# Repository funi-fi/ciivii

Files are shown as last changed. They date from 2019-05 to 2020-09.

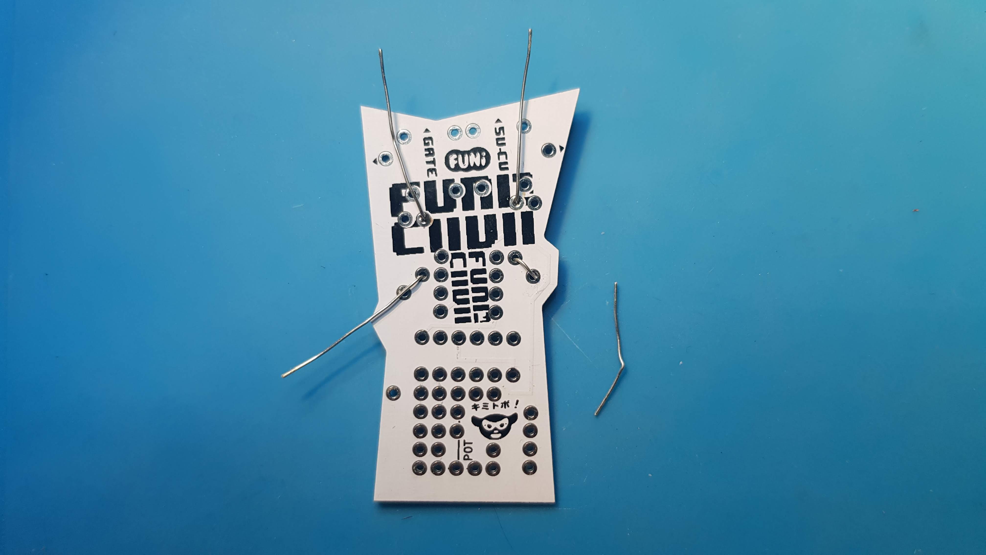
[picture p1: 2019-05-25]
Pics/CiiVii_Solder_Guide/20190522_220450.jpg

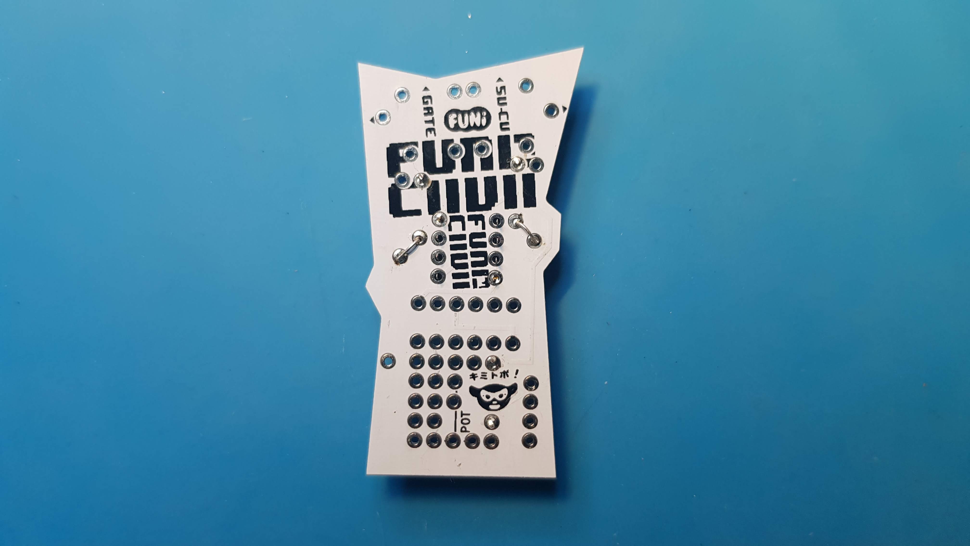
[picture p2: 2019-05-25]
Pics/CiiVii_Solder_Guide/20190522_221058.jpg

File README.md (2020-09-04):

# Funifi CiiVii
### Analog synth CV & gate controller




### Compact CV & gate controller

FuniFi CiiVii is a compact, programmable control voltage (0-5V CV&gate) controller for synthesizers with analog inputs. There is a popular ATtiny85 microcontroller in the heart of the device which can be progrmmed with Arduino IDE and collection of example patches for sending analog voltages via 12Bit DAC and protective OpAmp. Assembly is easy, just a handful of inecxpensive componets and through-hole board layout. 

Funifi CiiVii is shines with semimodular synths or small Eurorack kits, where extra CV or Gate control is welcome without expensive or large external devices. One CV output 0-5V and one gate output can be programmed to do whatever you want them to do. Just randomising the analog voltage seem to give hours of fun when plugged to various inputs in the analog synthesiser.

### How to get it

There will be DIY kits available when next round of testing has cleared some concerns. The circuit can be build on breadboard very easily for the hasty & geeky ones. If you would be interested in beta testing either the soldering, or coding, or both, don't hesitate to contact, few test kits will be avilable shortly.

### Make it

Follow the guides in the Github Wiki: https://github.com/funi-fi/ciivii/wiki

Digistump Arduino guide
https://digistump.com/wiki/digispark/tutorials/connecting

### Bill of Materials

TBD

### Open hardware

Funifi CiiVIi is open source hardware and open source software, in short do whatever you like with them, as long as you share your derivatives under same granted freedom.

### Proto-alert

Use at yuour own risk, no guarantee can be granted for unikely but possible damage to the device itself or where it is connected. CiiVii is a prototype. It has been tested but there is a lot of room for improvement. Below are few issues on the todo list. All tips & suggestions welcome.

Please check the open issues here:
https://github.com/funi-fi/ciivii/issues/1

### To-do

~~explore OpAmp resistor values for better voltage range~~
- explore Attiny85 firmware variation for uploading code without disconneting the device (/reset button?)
- source better disc potentimeter with 3pin/2.54pitch footprint
- scale potentiometer values for wider range in the lower resistancies
- BOM

--------

### Links

For controlling MIDI, check out FuniFi Midistik: 
https://github.com/funi-fi/midistik

FuniFi Playful DIY synth accessories
https://www.instagram.com/funifimusic/

Board manufactured by PCBWay
https://www.pcbway.com/project/shareproject/Funifi_CiiVIi.html

### Hardware Version history
- V0.1 12.4.2019

- V0.1 15.4.2018

### Acknowedgements
For me, this journey started in Tapei, deep bow for Dimension Plus for hosting several gatherings
http://dimensionplus.co/en/index.html

The main source for new knowledge on DIY PCB & Workshopology from Marc Dusseiller & 8BitMixtape hackers

http://www.dusseiller.ch/labs/

http://neo.8bitmixtape.cc/

Amazing SVG2Shenzhem Inkscape PCB design tool by Budi Prakosa

https://github.com/badgeek/svg2shenzhen

https://www.patreon.com/badgeek/posts

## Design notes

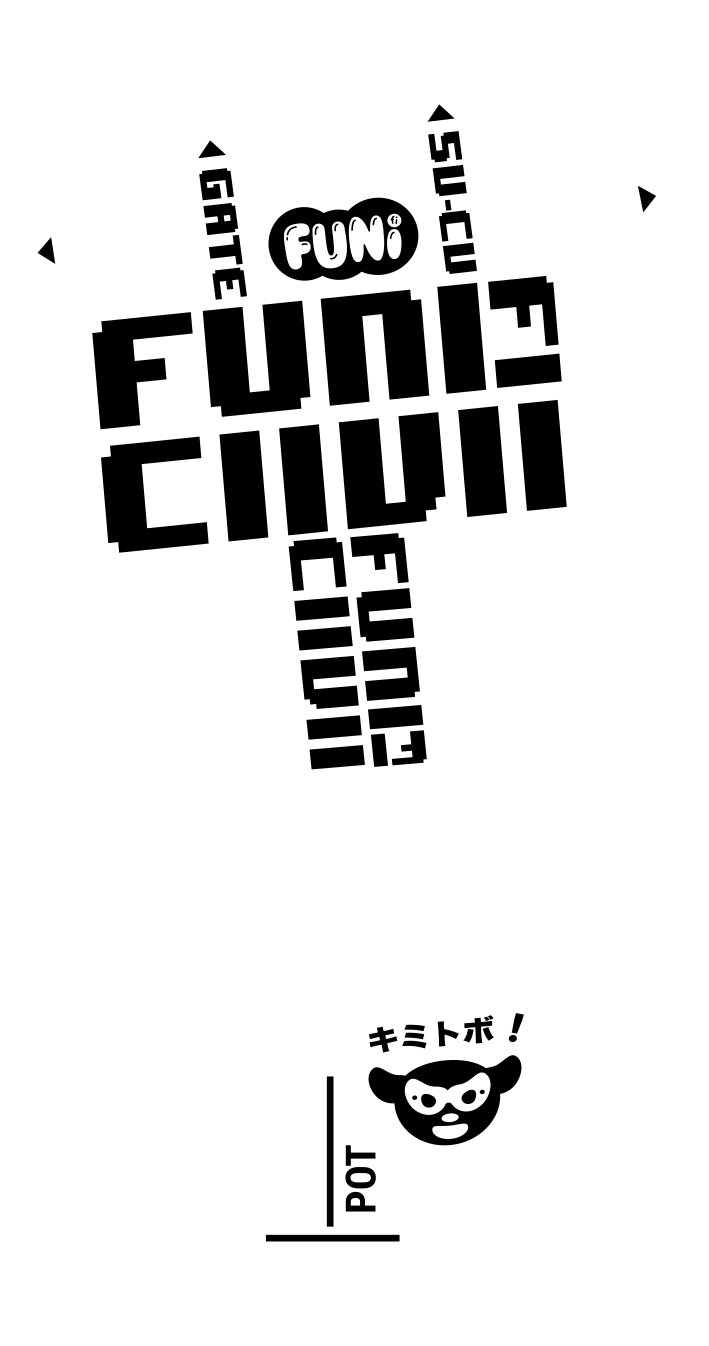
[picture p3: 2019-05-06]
Hardware/.svg2shenzhen-cache/images/F.Silk_g29462.png

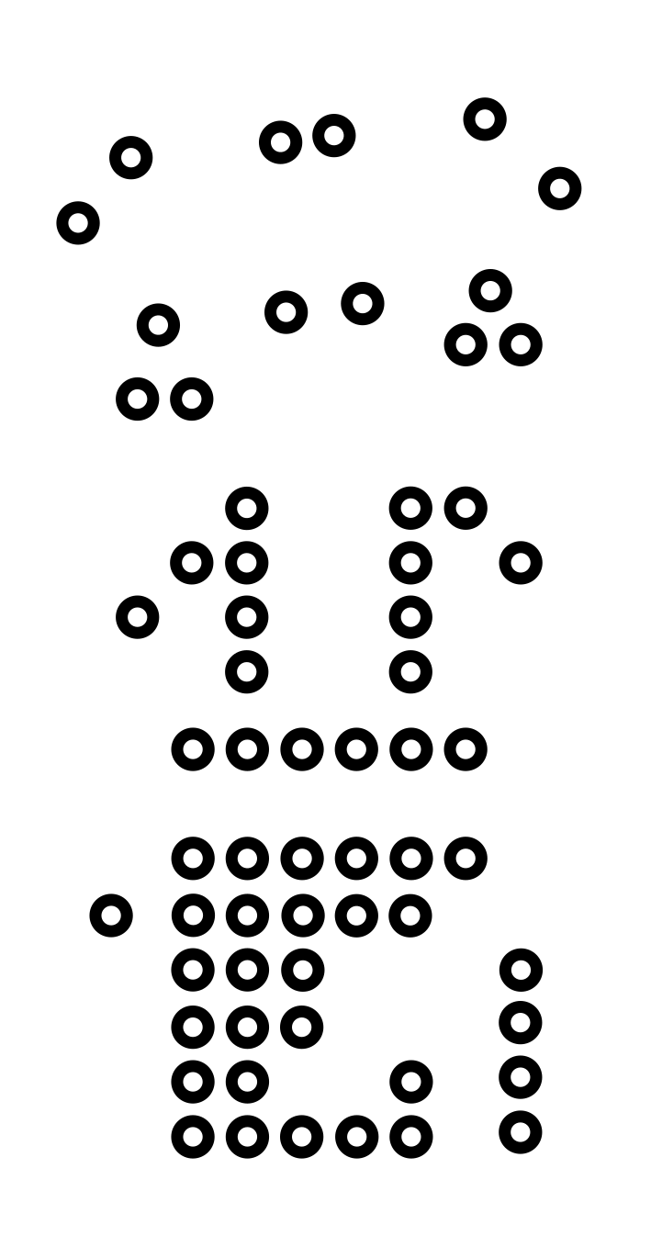
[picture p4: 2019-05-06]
Hardware/.svg2shenzhen-cache/images/B.Mask_g29454.png

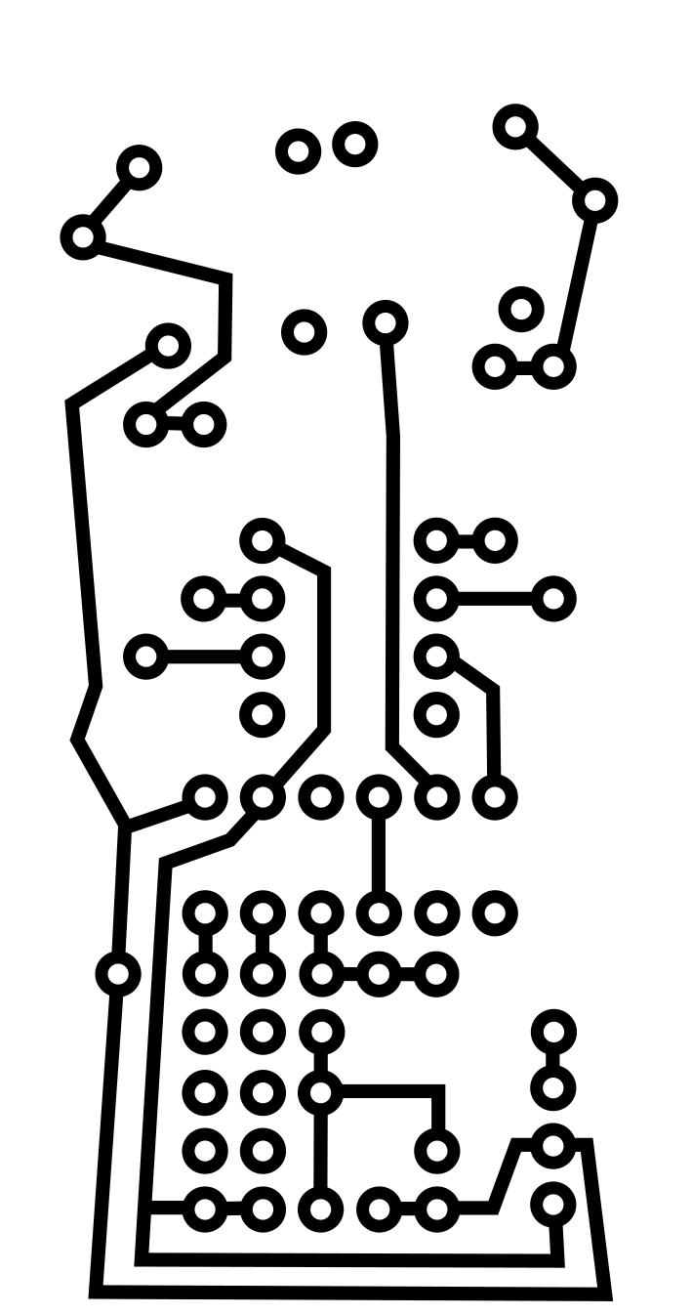
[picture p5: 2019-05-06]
Hardware/.svg2shenzhen-cache/images/B.Cu_g29452.png

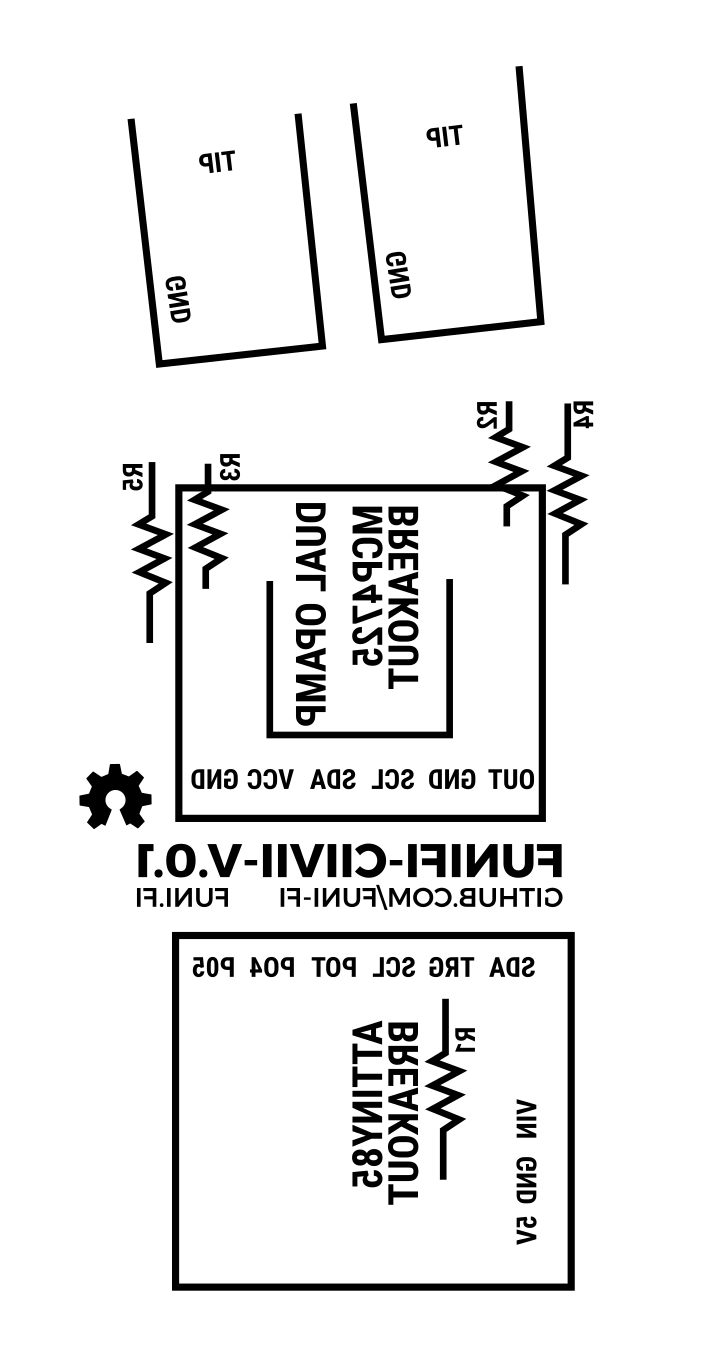
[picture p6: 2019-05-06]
Hardware/.svg2shenzhen-cache/images/B.Silk_g29456.png

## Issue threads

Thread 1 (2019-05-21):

OpAmp resistors decrease the output range

funi-fi, 2019-05-21:
OpMap feedback resistors decrease the output range to about 0-3V.

funi-fi, 2019-05-21:
R4 & R5 feedback resistors are not needed, but OpAmp inverted inputs (-) need connection to outputs. This is easiest leaving bit of resistor leg for R2 & R3 through the hole from the OpAmp output and solder the leg to the nearby inverted inputs. See the pic.:

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

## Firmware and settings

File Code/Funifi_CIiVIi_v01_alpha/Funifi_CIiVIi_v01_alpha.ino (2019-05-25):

  /*

  FUNI.FI CIIVII, HARDWARE VERSION 0.1
  _________ .__.______   ____.__.__ 
  \_   ___ \|__|__\   \ /   /|__|__|
  /    \  \/|  |  |\   Y   / |  |  |
  \     \___|  |  | \     /  |  |  |
   \______  /__|__|  \___/   |__|__|
          \/   
               
  ATTiny85 Pins
  ===================
                                 _______
                                |   U   |                                     
         (available) D5/A0  PB5-|       |- VCC                                
              Pot -> D3/A3  PB3-| ATTINY|- PB2  D2/A1 <- DAC I2C SCL
         (available) D4/A2  PB4-|   85  |- PB1  D1    -> Gate out
                            GND-|       |- PB0  D0    -> DAC I2C SDA
                                |_______|
  Digispark pin order
  ===================                     

  P5  Available D5/A0 / Reset (Some Digistump clones need firmware update for enabling D/A
  P4  Available D4/A3 / PWM 
  P3  A3    Analog in, pot
  P2  SCL   To DAC clock
  P1  D1    Gate out
  P0  SDA   To DAC data


  * Funi.fi CV randomiser experimentations by Tuomo Tammenpää (@kimitobo)
    https://github.com/funi-fi
    
  * MCP4725 DAC 12Bit bithsift lookup table code based on code written by Mark VandeWettering:
    http://brainwagon.org/2011/02/24/arduino-mcp4725-breakout-board/
    Discovered via Sparkfun MCP4725 hookup guide
    https://learn.sparkfun.com/tutorials/mcp4725-digital-to-analog-converter-hookup-guide

  * SVG-to-Shenzhen Inkscape to Kicad DIY PCB pipeline by Budi Prakosa
    https://github.com/badgeek/svg2shenzhen

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
 */

#include <TinyWireM.h>            // I2C library for Attiny85
#define MCP4725_ADDR 0x60         // Notice! MCP4725 can be modified to address 0x61 soldering the bridge

#define POTI          A3          // P3(A3) pin on Digispark
#define GATE_OUT      1           // P1 pin on Digispark
#define GATE_TIME     3           // Gate duration
#define BUFFER        10          // Minimum delay for sending the value to DAC
#define POT_MIN       570         // 10K disc pot min value: 510 / 570

uint16_t pitch = 0;               // Variable for pitch
uint16_t deg = 0;                 // Variable for degree in sinewave 

int tunetab[57] =  // 0 to 5V semitone every 73(ish) within 12bits (0-4095)
{
  0, 73, 146, 219, 292, 365, 438, 511, 584, 657, 730, 803,                           
  876, 949, 1022, 1095, 1168, 1241, 1314, 1387, 1460, 1533, 1606, 1679,
  1752, 1825, 1898, 1971, 2044, 2117, 2190, 2263, 2336, 2409, 2482, 2555, 
  2620, 2701, 2774, 2847, 2920, 2993, 3066, 3139, 3212, 3285, 3358, 3431,
  3504, 3577, 3650, 3723, 3796, 3869, 3942, 4015, 4088
};


// Semitones for various scales in shorter arrays. Use: pick a (scale)position in ocatave and add octave in 12, 24, 48 ... 
// See "CV from tables" -section below

int pentatab[5] =                               
{
  0, 3, 5, 7, 10                                    // Root, 3rd, 5th, 7th, 10th every octave
};

int bluestab[7] =  
{
  0, 3, 5, 6, 7, 10, 11                             // Blues scale
};

int fivetab[2] =  
{
  0, 5                                              // Root & 5th
};

int majortab[7] =  
{
  0, 2, 4, 5, 7, 9, 11                              // Major scale
};

int delaytab[12] =  
{
  1, 1, 1, 1, 1, 1, 1, 1, 1, 2, 4, 8                // Pause multipliers, emphasis on short
};


void setup() {
  TinyWireM.begin(); 
  pinMode(POTI, INPUT);
  pinMode(GATE_OUT, OUTPUT);
  digitalWrite(GATE_OUT, LOW);
}

uint16_t analogReadScaled()                          // Scale pot values, you can play mapping etc here
{                                  
  uint16_t value = analogRead(POTI);                 // pot returns values 510(POT_MIN) - 682 (disc pot)

  // Option A: Scale pot value range to 0 - POT_MIN, multiply by 5, force positive
  uint16_t scaled = abs(value - POT_MIN)*5;                      
  // Option B: Same as above, but multiply by one of the delaytab coefficients instead of constant 5
  // uint16_t scaled = abs(value - POT_MIN)*delaytab[random(11)];    // randomise note pauses with 1,2,4,8 multiplier
  
  return scaled;                                    // x5 multiplier for more exponential reduction in speed
}
  

// ------------------------------------------------- CV from tables (Send to tableToDac)


void randomTable() {                                // random semitone
  pitch = random(0, 56);
  tableToDac(pitch);  
}

void pentaScale() {
  pitch = pentatab[random(4)] + random(6)*12;       // random note from scale + random ocatve(1-5)
  tableToDac(pitch);  
}

void bluesScale() {
  pitch = bluestab[random(6)] + random(6)*12;       // random note from scale + random ocatve(1-5)
  tableToDac(pitch);
}

void majorScale() {
  pitch = majortab[random(6)] + random(6)*12;       // random note from scale + random ocatve(1-5)
  tableToDac(pitch);
}

void fifthScale() {
  pitch = fivetab[random(1)] + random(6)*12;       // random note from scale + random ocatve(1-5)
  tableToDac(pitch);
}

void octaScale() {
  pitch = random(5)*12;                             // random ocatve(1-4)
  tableToDac(pitch);
}


// ------------------------------------------------- CV Functions (Send to valueToDac)

void lowFrequencyOscillator() {
  int value = (sin(DEG_TO_RAD * deg)*2047)+2047;    // sinewave (from 0-360deg) -1.0 to 1.0 scaled 0 to 4095
  valueToDac(value);
  deg = deg + 2;
  if (deg > 360) deg = 0;
}

void randomVoltage() {                              // random voltage (0-5V, 12bits, between 0 and 4095)
  uint32_t cvOut = random(0, 4095);
  valueToDac(cvOut);  
}

void rampVoltage() {                                // ramp voltage (from 0-5V, 12bits, from 0 to 4095
  for (uint32_t cvOut = 0; cvOut <= 4095; cvOut++) {
    valueToDac(cvOut);  
  }
}

// ------------------------------------------------- Send GATE & CV

void gateTrigger() {
  digitalWrite(GATE_OUT, HIGH);
  delay(GATE_TIME);
  digitalWrite(GATE_OUT, LOW);
}

void tableToDac(uint32_t lookup) {                  // Send values to DAC from the tables above
  TinyWireM.beginTransmission(MCP4725_ADDR);
  TinyWireM.write(64);                              // Command to update the DAC
  TinyWireM.write(tunetab[lookup] >> 4);            // 12Bits are shifted to DAC in two sets, 8 most significant bits
  TinyWireM.write((tunetab[lookup] & 15) << 4);     // ... and 4 least significant bits  
  TinyWireM.endTransmission();
}

void valueToDac(uint32_t lookup) {                  // Send values directly to DAC
  TinyWireM.beginTransmission(MCP4725_ADDR);
  TinyWireM.write(64);                              // Command to update the DAC
  TinyWireM.write(lookup >> 4);                     // 12Bits are shifted to DAC in two sets,  8 most significant bits
  TinyWireM.write((lookup & 15) << 4);              // ... and 4 least significant bits
  TinyWireM.endTransmission();
}

// ------------------------------------------------- LOOP

void loop() {                                       // Try different scales here

  //fifthScale();
  octaScale();
  //pentaScale();
  //majorScale();
  //bluesScale();
  //randomTable();
  //randomVoltage();
  //rampVoltage();
  
  delay(BUFFER);                                    // Buffer time for sending CV
  gateTrigger();                                    // Send Gate triggerS
  delay(analogReadScaled());                        // Speed (pauses between notes) control from Pot
}

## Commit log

2019-05-06 added hardware files
    [CiiVIi_Dongle_Production_PCB-B.Cu.gbr, CiiVIi_Dongle_Production_PCB-B.Mask.gbr, CiiVIi_Dongle_Production_PCB-B.SilkS.gbr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]
2019-05-25 Solder guide pics added

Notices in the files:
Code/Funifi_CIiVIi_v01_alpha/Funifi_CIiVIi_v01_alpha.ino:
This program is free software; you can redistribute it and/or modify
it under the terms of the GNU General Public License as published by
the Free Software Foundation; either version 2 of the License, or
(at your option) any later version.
